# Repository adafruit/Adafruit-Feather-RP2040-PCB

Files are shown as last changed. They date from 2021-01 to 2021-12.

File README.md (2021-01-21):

# Adafruit-Feather-RP2040-PCB

Feather RP2040

Open source PCB files for Feather RP2040

PCB format is EagleCAD schematic and board layout

For more details, check out the product pages at

   * https://www.adafruit.com/products/4884

**We are releasing these files so folks can start creating custom designs based on the RP2040 chip. This design has been built and tested successfully**

Adafruit invests time and resources providing this open source design, 
please support Adafruit and open-source hardware by purchasing 
products from Adafruit!

Designed by Adafruit Industries.  
Creative Commons Attribution, Share-Alike license, check license.txt for more information
All text above must be included in any redistribution

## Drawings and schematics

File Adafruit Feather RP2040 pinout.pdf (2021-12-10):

# Feather RP2040

## https://www.adafruit.com/product/4884

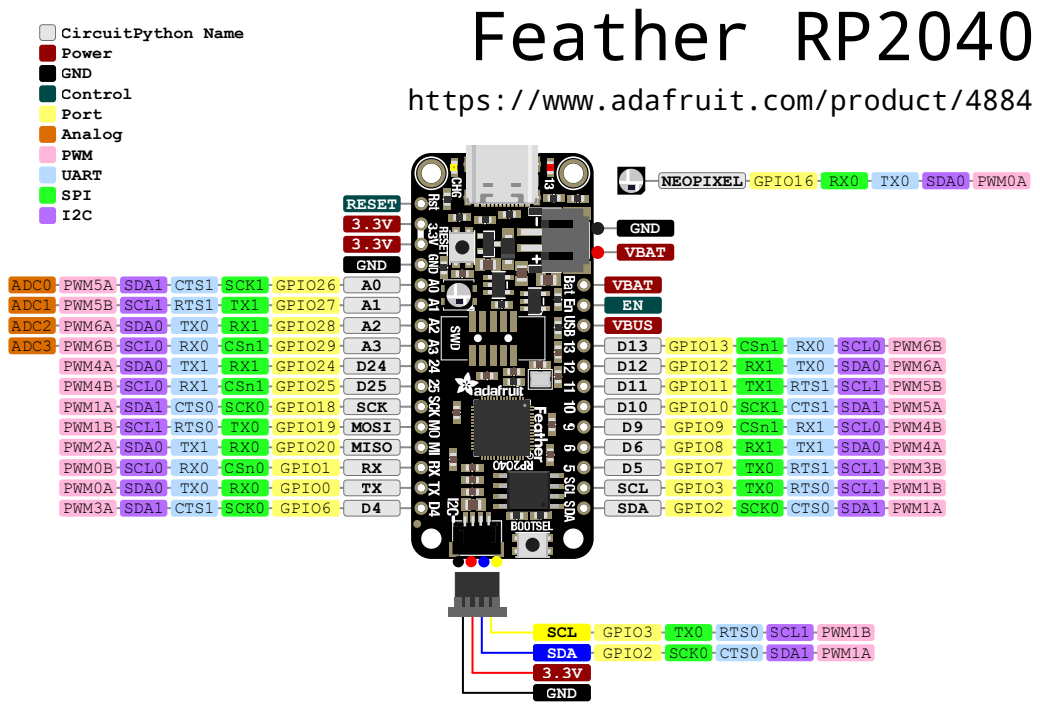
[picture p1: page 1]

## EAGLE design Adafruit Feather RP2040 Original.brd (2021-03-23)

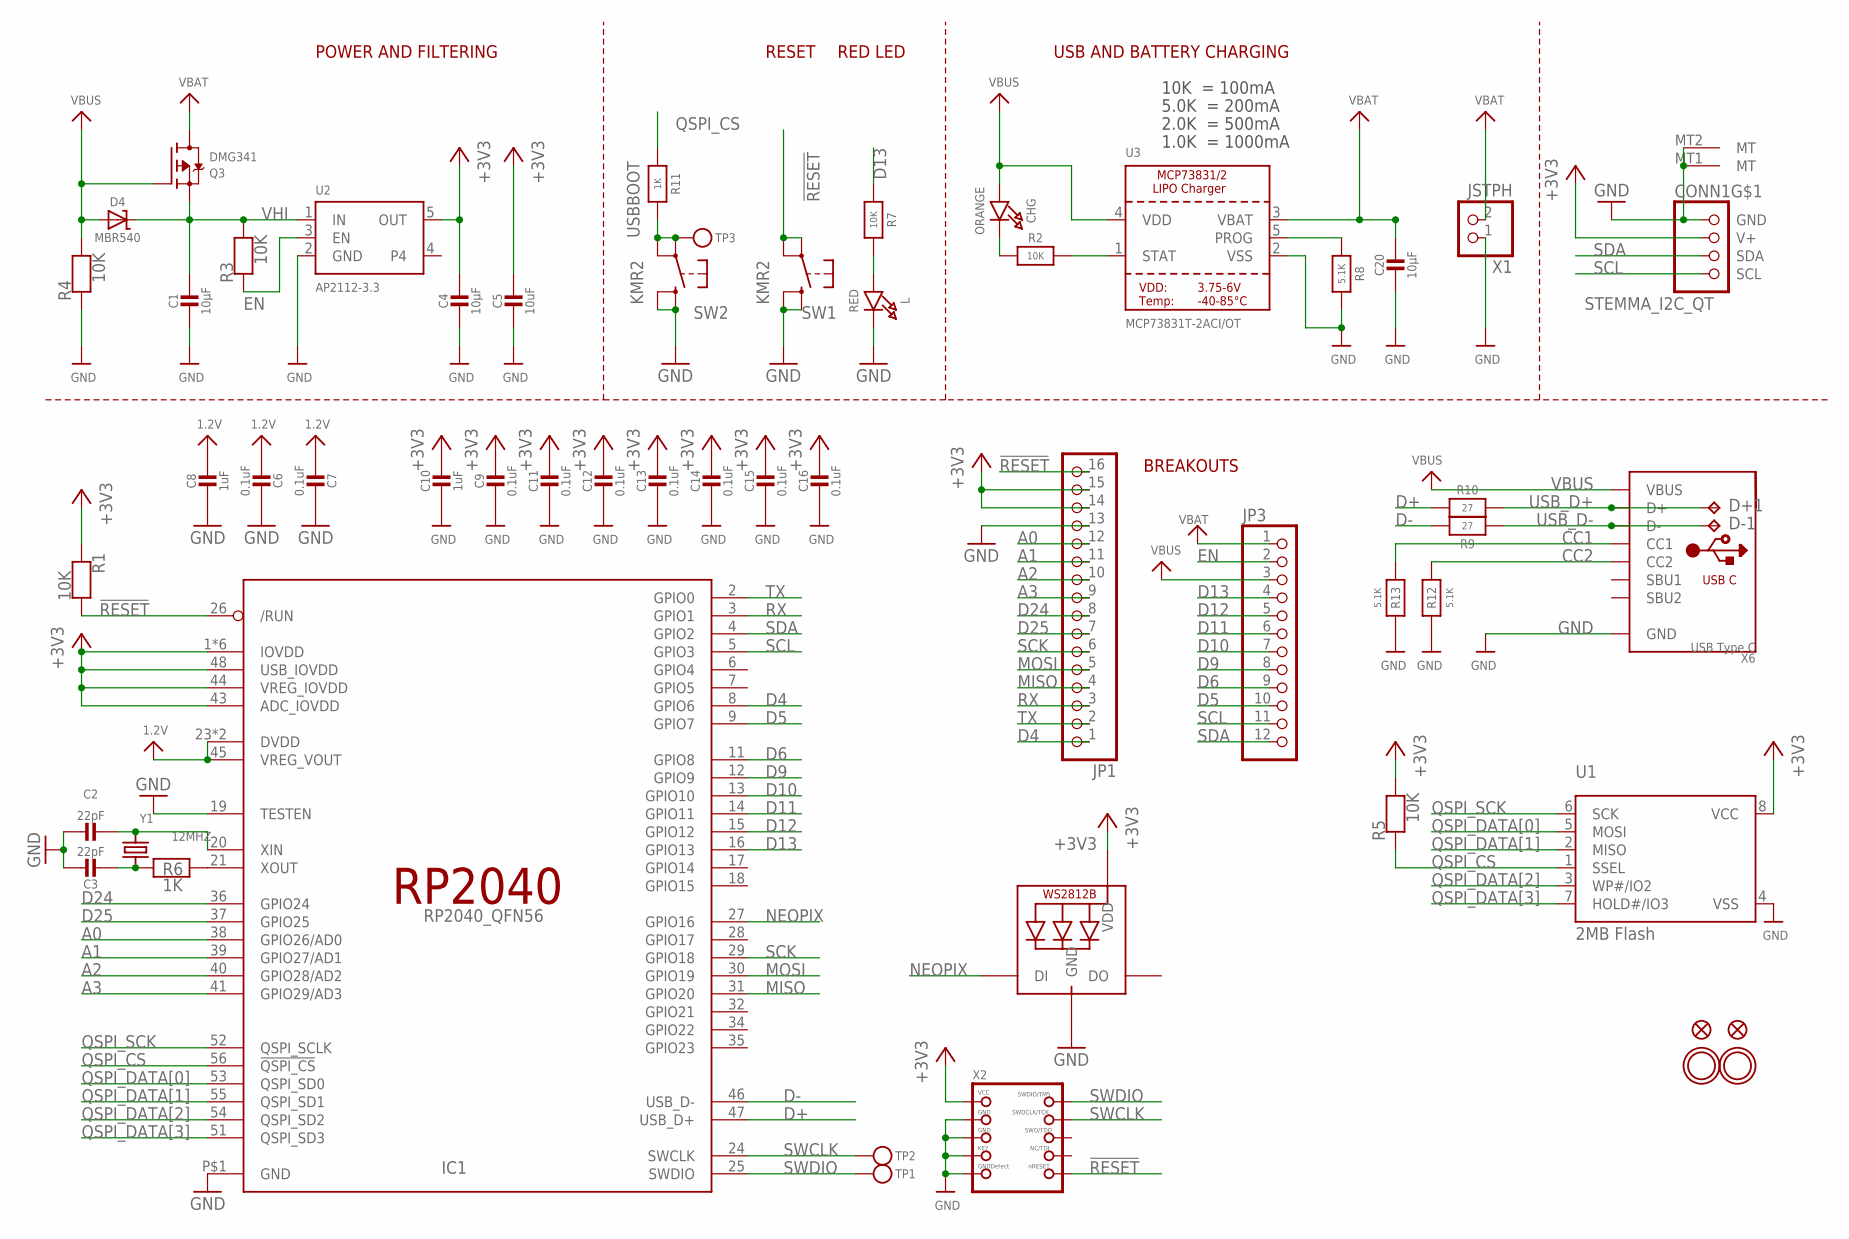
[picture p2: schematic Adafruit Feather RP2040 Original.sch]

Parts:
C1, C4, C20: 10µF; 0805-NO
C2, C3: 22pF; 0603-NO
C5: 10uF; 0805-NO
C6, C7, C9, C11, C12, C13, C14, C15, C16: 0.1uF; 0603-NO
C8, C10: 1uF; 0603-NO
CHG: ORANGE; CHIPLED_0603_NOOUTLINE
CONN1: STEMMA_I2C_QT; JST_SH4
D4: MBR540; SOD-123
D+1: TPB1,27; B1,27
D-1: TPB1,27; B1,27
IC1: RP2040_QFN56; QFN56_7MM_REDUCEDEPAD
JP1: HEADER-1X16ROUND; 1X16_ROUND
JP3: HEADER-1X12; 1X12_ROUND
L: RED; CHIPLED_0603_NOOUTLINE
LED1: WS2812B3535; LED3535
Q3: DMG341; SOT23-R
R1, R2, R3, R4, R5, R7: 10K; 0603-NO
R6, R11: 1K; 0603-NO
R8, R12, R13: 5.1K; 0603-NO
R9, R10: 27; 0603-NO
SW1, SW2: KMR2; BTN_KMR2_4.6X2.8
TP1, TP2, TP3: TESTPOINTROUND1.5MMNO; TESTPOINT_ROUND_1.5MM_NO
U1: 2MB Flash; SOIC8_208MIL
U2: AP2112-3.3; SOT23-5@1
U3: MCP73831T-2ACI/OT; SOT23-5
U$31, U$32: MOUNTINGHOLE2.5; MOUNTINGHOLE_2.5_PLATED
U$34, U$35: FIDUCIAL_1MM
X1: JSTPH; JSTPH2_BATT
X2: JTAG-CORTEXBOXPOSTS; 2X05_1.27MM_BOX_POSTS
X6: USB Type C; USB_C_CUSB31-CFM2AX-01-X
Y1: 12MHZ; CRYSTAL_2.5X2

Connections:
1.2V: C6.2, C7.2, C8.1, IC1.23 (DVDD), IC1.45 (VREG_VOUT), IC1.50 (DVDD)
!RESET: IC1.26 (/RUN), JP1.16, R1.2, SW1.A, SW1.A' (P1), X2.10 (NRESET)
+3V3: C4.1, C5.1, C9.1, C10.1, C11.1, C12.1, C13.1, C14.1, C15.1, C16.1, CONN1.2 (V+), IC1.1 (IOVDD), IC1.10 (IOVDD), IC1.22 (IOVDD), IC1.33 (IOVDD), IC1.42 (IOVDD), IC1.43 (ADC_IOVDD), IC1.44 (VREG_IOVDD), IC1.48 (USB_IOVDD), IC1.49 (IOVDD), JP1.14, JP1.15, LED1.2 (VDD), R1.1, R5.2, U1.8 (VCC), U2.5 (OUT), X2.1 (VCC)
A0: IC1.38 (GPIO26/AD0), JP1.12
A1: IC1.39 (GPIO27/AD1), JP1.11
A2: IC1.40 (GPIO28/AD2), JP1.10
A3: IC1.41 (GPIO29/AD3), JP1.9
CC1: R13.2, X6.A5 (CC1)
CC2: R12.2, X6.B5 (CC2)
D4: IC1.8 (GPIO6), JP1.1
D5: IC1.9 (GPIO7), JP3.10
D6: IC1.11 (GPIO8), JP3.9
D9: IC1.12 (GPIO9), JP3.8
D10: IC1.13 (GPIO10), JP3.7
D11: IC1.14 (GPIO11), JP3.6
D12: IC1.15 (GPIO12), JP3.5
D13: IC1.16 (GPIO13), JP3.4, R7.1
D24: IC1.36 (GPIO24), JP1.8
D25: IC1.37 (GPIO25), JP1.7
D+: IC1.47 (USB_D+), R10.2
D-: IC1.46 (USB_D-), R9.2
EN: JP3.2, R3.1, U2.3 (EN)
GND: C1.2, C2.1, C3.1, C4.2, C5.2, C6.1, C7.1, C8.2, C9.2, C10.2, C11.2, C12.2, C13.2, C14.2, C15.2, C16.2, C20.2, CONN1.1 (GND), CONN1.MT1 (MT), CONN1.MT2 (MT), IC1.19 (TESTEN), IC1.P$1 (GND), JP1.13, L.C, LED1.4 (GND), R4.1, R8.2, R12.1, R13.1, SW1.B (S), SW1.B' (S1), SW2.B (S), SW2.B' (S1), U1.4 (VSS), U2.2 (GND), U3.2 (VSS), X1.1, X2.3 (GND), X2.5 (GND), X2.7 (KEY), X2.9 (GNDDETECT), X6.A1B12 (GND), X6.B1A12 (GND)
MISO: IC1.31 (GPIO20), JP1.4
MOSI: IC1.30 (GPIO19), JP1.5
unnamed: CHG.C, R2.1
unnamed: L.A, R7.2
unnamed: R2.2, U3.1 (STAT)
unnamed: R8.1, U3.5 (PROG)
unnamed: C2.2, IC1.20 (XIN), Y1.3 (2)
unnamed: C3.2, R6.1, Y1.1
unnamed: IC1.21 (XOUT), R6.2
NEOPIX: IC1.27 (GPIO16), LED1.1 (DI)
QSPI_CS: IC1.56 (!QSPI_CS), R5.1, R11.1, U1.1 (SSEL)
QSPI_DATA[0]: IC1.53 (QSPI_SD0), U1.5 (MOSI)
QSPI_DATA[1]: IC1.55 (QSPI_SD1), U1.2 (MISO)
QSPI_DATA[2]: IC1.54 (QSPI_SD2), U1.3 (WP#/IO2)
QSPI_DATA[3]: IC1.51 (QSPI_SD3), U1.7 (HOLD#/IO3)
QSPI_SCK: IC1.52 (QSPI_SCLK), U1.6 (SCK)
RX: IC1.3 (GPIO1), JP1.3
SCK: IC1.29 (GPIO18), JP1.6
SCL: CONN1.4 (SCL), IC1.5 (GPIO3), JP3.11
SDA: CONN1.3 (SDA), IC1.4 (GPIO2), JP3.12
SWCLK: IC1.24 (SWCLK), TP2.P$1, X2.4 (SWDCLK)
SWDIO: IC1.25 (SWDIO), TP1.P$1, X2.2 (SWDIO)
TX: IC1.2 (GPIO0), JP1.2
USBBOOT: R11.2, SW2.A, SW2.A' (P1), TP3.P$1
USB_D+: D+1.TP, R10.1, X6.A6 (D+), X6.B6 (D+)
USB_D-: D-1.TP, R9.1, X6.A7 (D-), X6.B7 (D-)
VBAT: C20.1, JP3.1, Q3.3 (D), U3.3 (VBAT), X1.2
VBUS: CHG.A, D4.A, JP3.3, Q3.1 (G), R4.2, U3.4 (VDD), X6.A4B9 (VBUS), X6.B4A9 (VBUS)
VHI: C1.1, D4.C, Q3.2 (S), R3.2, U2.1 (IN)

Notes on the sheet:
POWER AND FILTERING
RESET
10K = 100mA
5.0K = 200mA
2.0K = 500mA
1.0K = 1000mA
USB AND BATTERY CHARGING
BREAKOUTS
RED LED

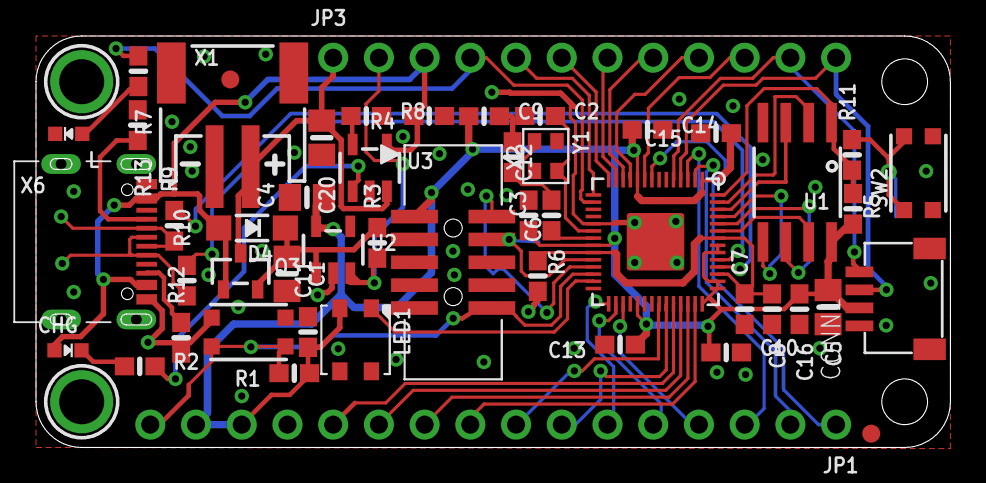
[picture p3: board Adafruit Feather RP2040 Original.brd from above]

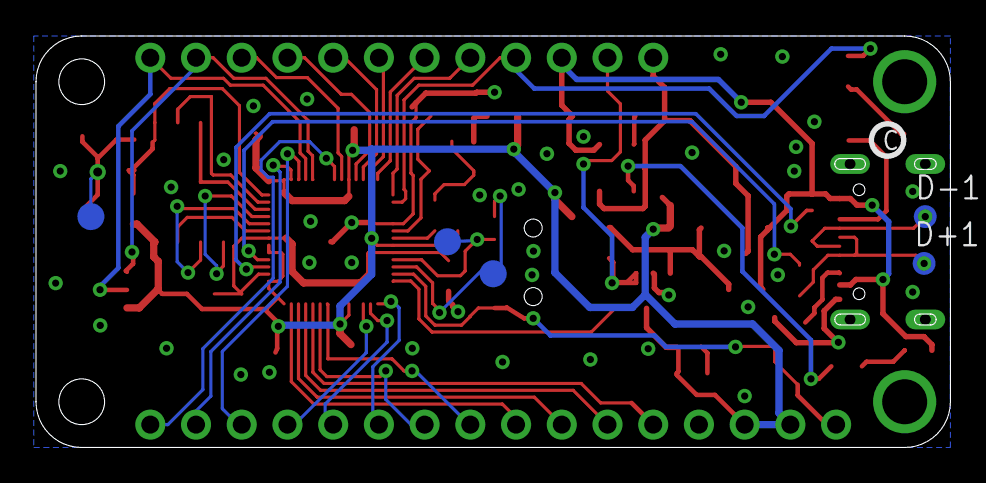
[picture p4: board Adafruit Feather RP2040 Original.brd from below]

Board: 2 copper layers, 50.8 x 22.9 mm, 60 parts (7 on the bottom side), 52 nets.

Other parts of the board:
U$1: RP2040_BOT
U$13: PCBFEAT-REV-040
U$43: RP2040_TOP

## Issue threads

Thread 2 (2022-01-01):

Pink Adafruit Feather RP2040 Board ID Issue?

tdawry, 2022-01-01:
I am not sure if this is the right place for this, as I am new to working with hardware (sorry!).

The [_Pink Adafruit Feather RP2040 - Free for orders $99 or more Product ID: 5299_](https://www.adafruit.com/product/5299) may have the incorrect _Board ID:_ as a default value.

- If _not_ updating, and connecting to the device via Thonny, the _Board ID:_ suggests it is a _Raspberry Pi Pico_ of no particular variant, and it is missing a number of libraries (like _board_). Connecting via a serial connection does work, but the missing libraries persist. On Windows 10 it does not show up as _CIRCUITPY_ (or anything else). The bootloader does show in Explorer if booting to it.

- Following the CircuitPython instructions on the Adafruit website leads to updating the firmware with a file such as _adafruit-circuitpython-adafruit_feather_rp2040-en_US-7.1.0.uf2_ but this fails. It presents errors such as _"ERROR thonny.plugins.micropython.backend: Crash in backend"_. Connecting via a serial connection does not seem to work or present an error here.

- Updating the _Board ID:_ to _adafruit_feather_rp2040_ and only then updating to the newest CircuitPython, _adafruit-circuitpython-adafruit_feather_rp2040-en_US-7.2.0-alpha.1.uf2_, seems to fix the main issues here. The board is still not accessible in Thonny but does show up in Explorer, and will allow for a _code.py_ to be copied over and executed.

PC settings with which this was tested:
_Edition	Windows 10 Education
Version	21H1
Installed on	‎7/‎6/‎2020
OS build	19043.1415
Experience	Windows Feature Experience Pack 120.2212.3920.0_

ladyada, 2022-01-01:
sounds like thonny isnt happy with circuitpython which is not too unsurprising. could always just try mu!

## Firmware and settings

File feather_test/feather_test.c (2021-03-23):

#define PICO_FLASH_SIZE_BYTES (2 * 1024 * 1024)

#include <stdio.h>
#include <math.h>
#include "pico/stdlib.h"
#include "hardware/gpio.h"
#include "hardware/adc.h"
#include "hardware/pio.h"
#include "hardware/clocks.h"
#include "ws2812.pio.h"


bool test_pins(uint pina, uint pinb);
#define UART_ID uart0

uint8_t allpins[] = {2, 3, 6, 7, 8, 9, 10, 11, 12, 13, 18, 19, 20, 24, 25, 29};
#define NUM_PINS sizeof(allpins)
#define PIN_NEOPIX 16
#define BRIGHTNESS 0.2


static inline void put_pixel(uint32_t pixel_grb) {
    pio_sm_put_blocking(pio0, 0, pixel_grb << 8u);
}

static inline uint32_t urgb_u32(uint8_t r, uint8_t g, uint8_t b) {
    return
            ((uint32_t) (r * BRIGHTNESS) << 8) |
            ((uint32_t) (g * BRIGHTNESS) << 16) |
            (uint32_t) (b * BRIGHTNESS);
}


uint32_t Wheel(uint8_t WheelPos) {
  if (WheelPos < 85) {
    return urgb_u32(WheelPos * 3, 255 - WheelPos * 3, 0);
  } else if(WheelPos < 170) {
    WheelPos -= 85;
    return urgb_u32(255 - WheelPos * 3, 0, WheelPos * 3);
  } else {
    WheelPos -= 170;
    return urgb_u32(0, WheelPos * 3, 255 - WheelPos * 3);
  }
}

int main()
{
  stdio_init_all();
  
  puts("Feather RP2040 demo & tester");

  // todo get free sm
  PIO pio = pio0;
  int sm = 0;
  uint offset = pio_add_program(pio, &ws2812_program);
  
  ws2812_program_init(pio, sm, offset, PIN_NEOPIX, 800000, true);
  
  // LED output
  gpio_init(13);
  gpio_set_dir(13, GPIO_OUT);

  uint8_t i=0;
  bool LED = false;

  while (1) {
    put_pixel(Wheel(i++));
    sleep_ms(10);
    if (i % 10 == 0) {
      gpio_put(13, LED);
      LED = !LED;
    }

    // check if we have a test command waiting
    if (uart_is_readable(UART_ID)) {
      uint8_t ch = uart_getc(UART_ID);
      if (ch == 0xAF) { // oh so ya wanna do a test?
        break;
      }
    }
  }


  for (int i=0; i<NUM_PINS; i++)  {
    printf("GPIO init %d\n", allpins[i]);
    gpio_init(allpins[i]);
  }
  adc_init();
  adc_gpio_init(26);
  adc_gpio_init(27);
  adc_gpio_init(28);


  printf("**Test GPIO!\n");
  
  while (1) {
    sleep_ms(100);
    if (! test_pins(13, 11)) continue; // D13 and D11
    if (! test_pins(12, 10)) continue; // D12 and D10
    if (! test_pins(9, 7)) continue;   // D9 and D5
    if (! test_pins(8, 3)) continue;  // D6 and SCL
    if (! test_pins(6, 2)) continue;  // D4 and SDA
    if (! test_pins(20, 24)) continue;  // MO and 24
    if (! test_pins(19, 25)) continue;  // MI and 25
    if (! test_pins(18, 29)) continue;  // SCK and A3

    // read 1/2 of VBAT, should be about 2.1V
    adc_select_input(0);
    float vbat = adc_read();
    vbat *= 3.3;
    vbat *= 2.0;
    vbat /= 4096.0;
    printf("VBat ADC = %0.1f V\n", vbat);
    if (fabs(vbat - 4.2) > 0.2) {
      printf("VBat should be 4.2V but isn't\n");
      continue;
    }

    // read 1/2 of VUSB, should be 2.5 V
    adc_select_input(2);
    float vusb = adc_read();
    vusb *= 3.3;
    vusb *= 2.0;
    vusb /= 4096.0;
    printf("VUSB ADC = %0.1f V\n", vusb);
    if ((vusb < 4.5) || (vusb > 5.5)) {
      printf("VUSB should be 5V but isn't\n");
      continue;
    }

    // read A1 should be ground
    adc_select_input(1);
    float vgnd = adc_read();
    vgnd *= 3.3;
    vgnd /= 4096.0;

    printf("ADC1 = %0.1f V\n", vgnd);
    if (vgnd > 0.2) {
      printf("ADC1 should be 0V but isn't\n");
      continue;
    }

    break;
  }

  printf("**GPIO+ADC OK!\n");

  return 0;
}


bool test_pins(uint a, uint b) {
  printf("testing GPIOpin %d and %d\n", a, b);

  // set both to inputs
  gpio_set_dir(a, GPIO_IN);
  gpio_set_dir(b, GPIO_IN);

  // turn on 'a' pullup
  gpio_pull_up(a);
  gpio_disable_pulls(b);

  sleep_ms(3);

  // verify neither are grounded
  if (! gpio_get(a) || ! gpio_get(b)) {
    printf("Ground test 1 fail\n");
    return false;
  }
  
 
  // make a an output, b with a pullup
  gpio_set_dir(a, GPIO_OUT);
  gpio_set_dir(b, GPIO_IN);

  gpio_disable_pulls(a);
  gpio_pull_up(b);

  gpio_put(a, false);

  sleep_ms(3);

  // make sure b is low
  if (gpio_get(b)) {
    printf("Low test fail on %d\n", b);
    return false;
  }

  // make b an output, a with a pullup
  gpio_set_dir(a, GPIO_IN);
  gpio_set_dir(b, GPIO_OUT);

  gpio_pull_up(a);
  gpio_disable_pulls(b);

  gpio_put(b, false);

  sleep_ms(3);

  // make sure a is low
  if (gpio_get(a)) {
    printf("Low test fail on %d\n", a);
    return false;
  }
 
  // a is an input, b is an output
  gpio_set_dir(a, GPIO_IN);
  gpio_set_dir(b, GPIO_OUT);

  gpio_pull_down(a);

  gpio_put(b, true);

  sleep_ms(3);

  // verify a is not grounded
  if (! gpio_get(a)) {
    printf("Ground2 test fail\n");
    return false;
  }
  
  // make sure no pins are shorted to pin a or b
  for (uint8_t i=0; i<NUM_PINS; i++)  {
    gpio_set_dir(allpins[i], GPIO_IN);
    gpio_pull_up(allpins[i]);
  }

  gpio_set_dir(a, GPIO_OUT);
  gpio_set_dir(b, GPIO_OUT);
  gpio_put(a, false);
  gpio_put(b, false);

  sleep_ms(3);

  for (uint8_t i=0; i<NUM_PINS; i++) {
    if ((allpins[i] == a) || (allpins[i] == b)) {
      continue;
    }

    //printf("\tPin #%d -> %d\n", allpins[i], gpio_get(allpins[i]));

    if (! gpio_get(allpins[i])) {
      printf("%d is shorted?\n", allpins[i]);
      return false;
    }
  }

  gpio_set_dir(a, GPIO_IN);
  gpio_disable_pulls(a);
  gpio_set_dir(b, GPIO_IN);
  gpio_disable_pulls(b);

  sleep_ms(3);

  return true;
}

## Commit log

2021-03-03 Add board files
    [Adafruit Feather RP2040.brd, Adafruit Feather RP2040.sch]
2022-12-02 Add new rev.
    [Adafruit Feather RP2040 Original.brd, Adafruit Feather RP2040 Original.sch, Adafruit Feather RP2040.sch]

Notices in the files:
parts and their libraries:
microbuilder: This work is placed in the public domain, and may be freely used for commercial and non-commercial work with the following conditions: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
